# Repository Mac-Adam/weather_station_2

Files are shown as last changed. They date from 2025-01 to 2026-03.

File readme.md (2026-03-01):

## 3D Printable weather station

This is the repository for my personal project, a weather station.
It is based on ESP32. You can view the source code in the weather station folder.
All the 3d models are available in the 3d models folder.
Folder old has the program for an older version of the design.
Folder tests has a few programs created to calibrate or test individual components.
The stations has following functionality:

- Temperature, humidity and pressure sensor
- Air quality sensor
- Custom wind speed meter
- Custom wind direction meter
- Custom rain meter with heating to measure snow

## Building And Running

Open the Weather_station project in arudino studio and program your ESP32.
Before programing, create a secrets.ino file:

```

#ifndef SECRETS

#define WIFINAME "Name of your WiFi"
#define PASSWORD "Your WiFi Password"
#define ID Unique ID
#define SERVERNAME "Url for your server"
#else

#define SECRETS
#endif
```

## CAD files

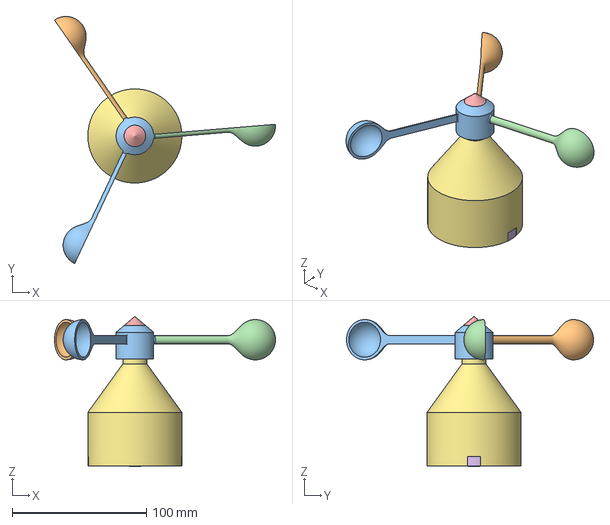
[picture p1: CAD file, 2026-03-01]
3dModels/assembly_speed.3mf
164.5 x 183.9 x 111.7 mm

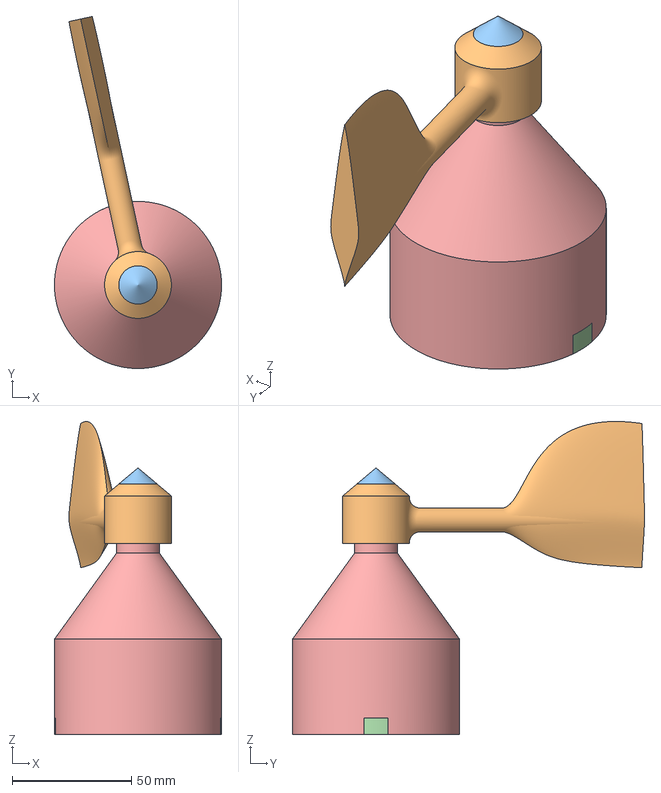
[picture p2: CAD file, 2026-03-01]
3dModels/assembly_direction.3mf
70.0 x 147.5 x 131.2 mm
new_shaft

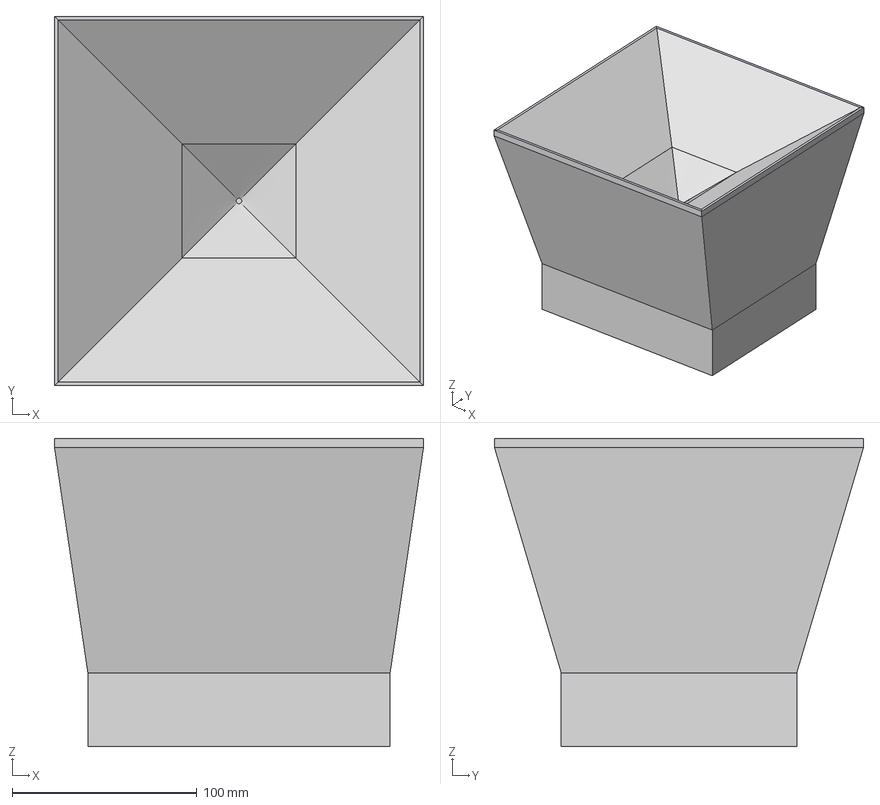
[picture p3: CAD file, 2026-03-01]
3dModels/assembly_rain.3mf
200.0 x 200.0 x 167.0 mm
base
inner1
inner2
inner3
inner4
inner_mid
outer1
outer2
outer3
outer4

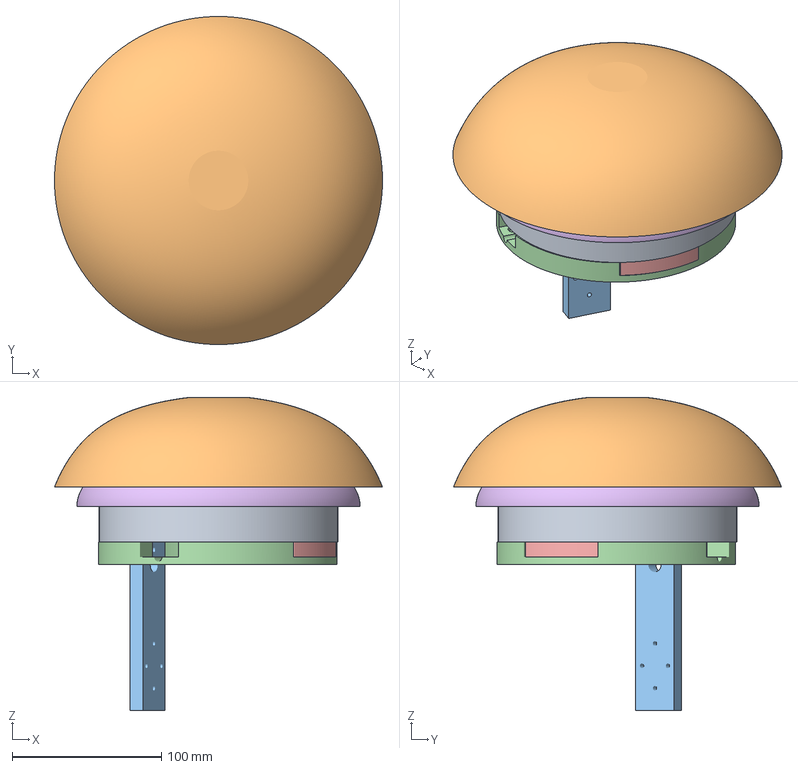
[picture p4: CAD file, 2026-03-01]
3dModels/assembly_hub.3mf
220.0 x 220.0 x 210.0 mm

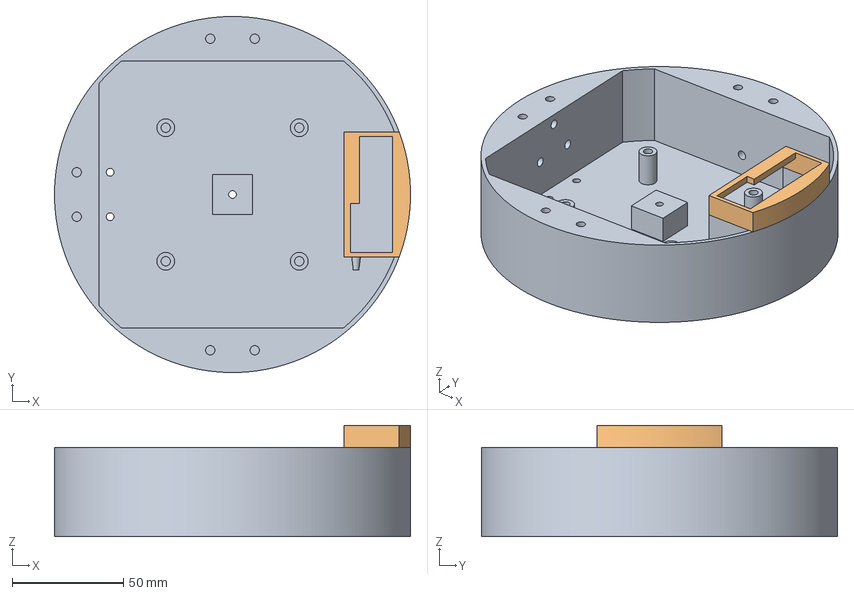
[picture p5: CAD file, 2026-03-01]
3dModels/hub/base_full.3mf
160.0 x 160.0 x 50.0 mm

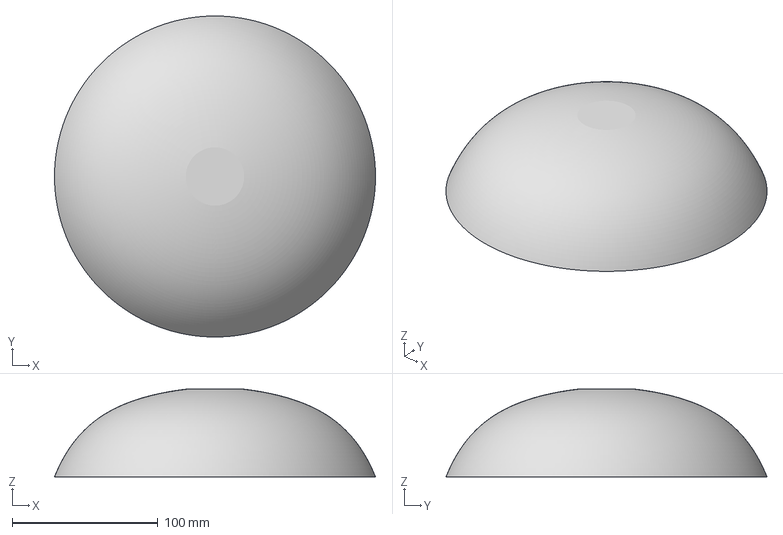
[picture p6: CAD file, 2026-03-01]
3dModels/hub/hat_1.3mf
220.0 x 220.0 x 60.0 mm

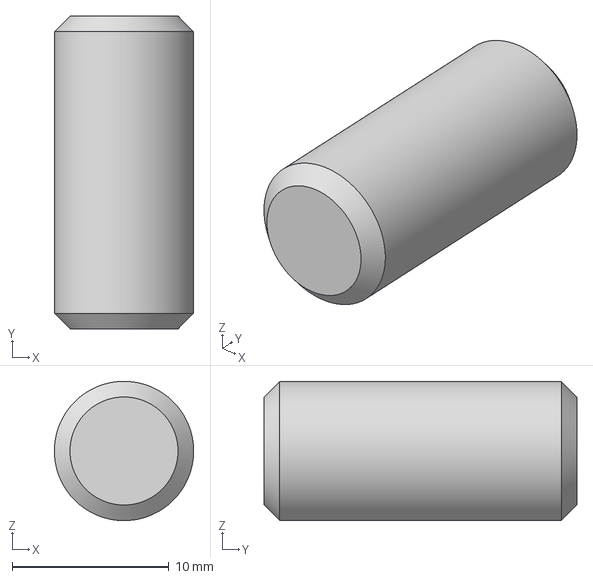
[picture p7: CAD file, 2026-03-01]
3dModels/rain/pin.3mf
8.90 x 20.0 x 8.90 mm

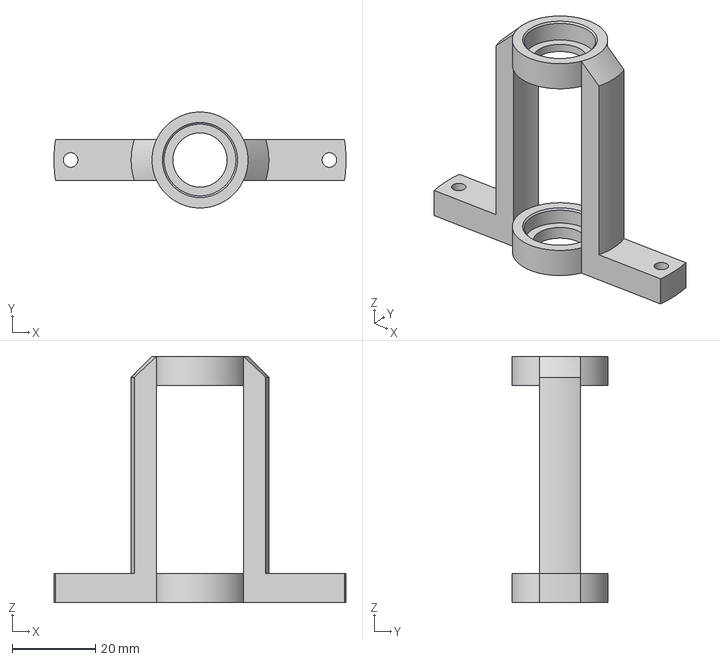
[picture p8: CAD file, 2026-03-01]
3dModels/wind/base_direction.3mf
70.0 x 23.0 x 59.0 mm

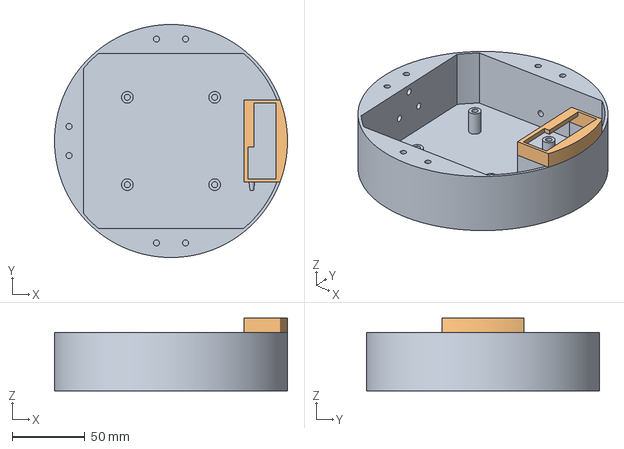
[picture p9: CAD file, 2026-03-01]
3dModels/hub/base_minimal.3mf
160.0 x 160.0 x 50.0 mm

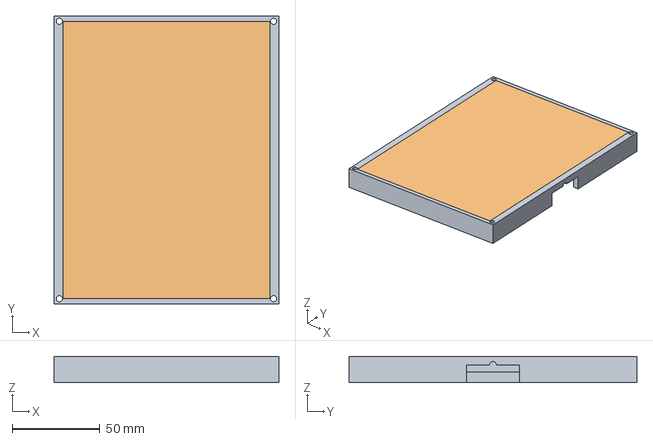
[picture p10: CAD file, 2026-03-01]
3dModels/rain/cover.3mf
128.0 x 164.0 x 15.0 mm

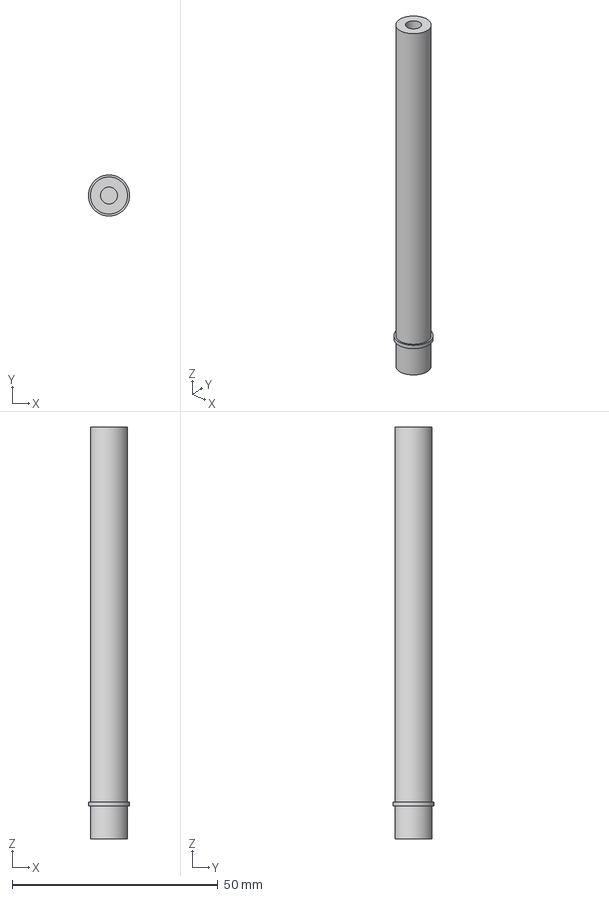
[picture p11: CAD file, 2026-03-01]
3dModels/wind/shaft_direction.3mf
10.0 x 10.0 x 100.0 mm

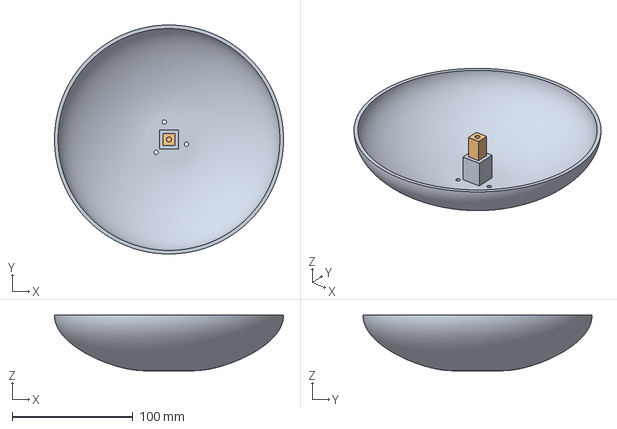
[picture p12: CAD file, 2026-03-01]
3dModels/hub/hat_2.3mf
190.0 x 190.0 x 46.1 mm

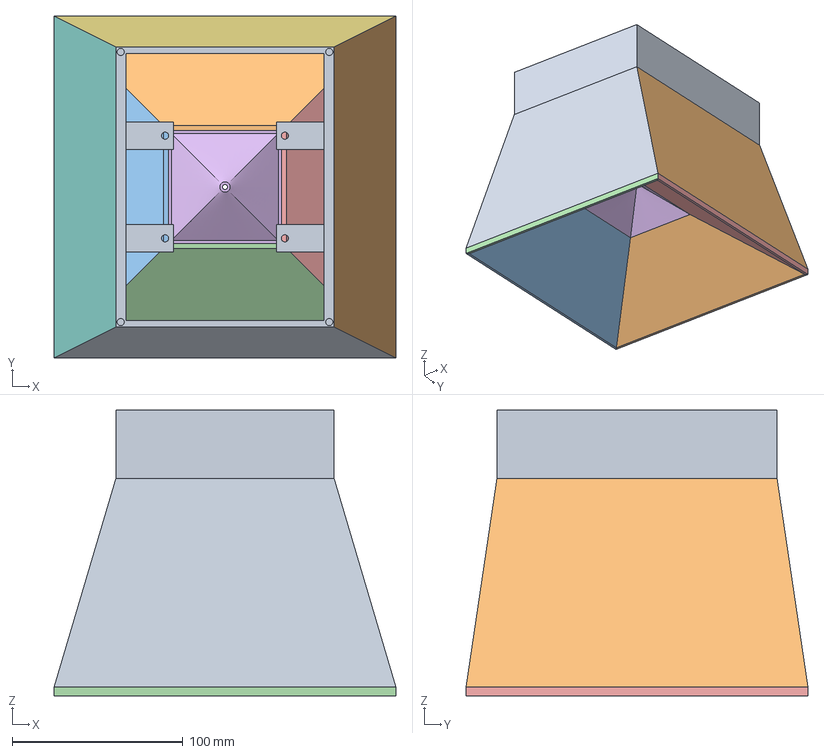
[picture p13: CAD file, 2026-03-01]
3dModels/rain/funnel.3mf
200.0 x 200.0 x 167.0 mm
base
inner1
inner2
inner3
inner4
inner_mid
outer1
outer2
outer3
outer4

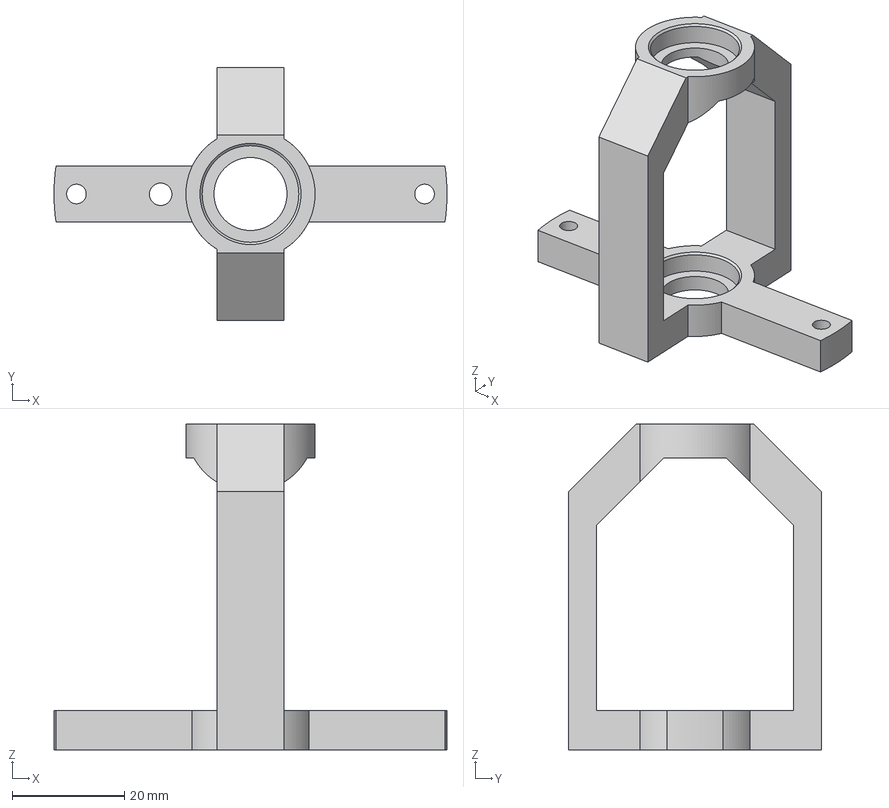
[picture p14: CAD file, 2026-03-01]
3dModels/wind/base_speed.3mf
70.0 x 45.0 x 58.0 mm

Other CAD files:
3dModels/hub/cover.3mf
3dModels/rain/pools.3mf
3dModels/wind/cover.3mf
3dModels/rain/mout.3mf
3dModels/hub/cover_minimal.3mf
3dModels/hub/mount.3mf
3dModels/rain/body.3mf
3dModels/rain/maget_holder.3mf
3dModels/rain/pin_holder.3mf
3dModels/wind/mount.3mf
3dModels/wind/shaft_speed.3mf
3dModels/wind/top_cover.3mf
3dModels/wind/top_direction.3mf
3dModels/wind/top_speed.3mf

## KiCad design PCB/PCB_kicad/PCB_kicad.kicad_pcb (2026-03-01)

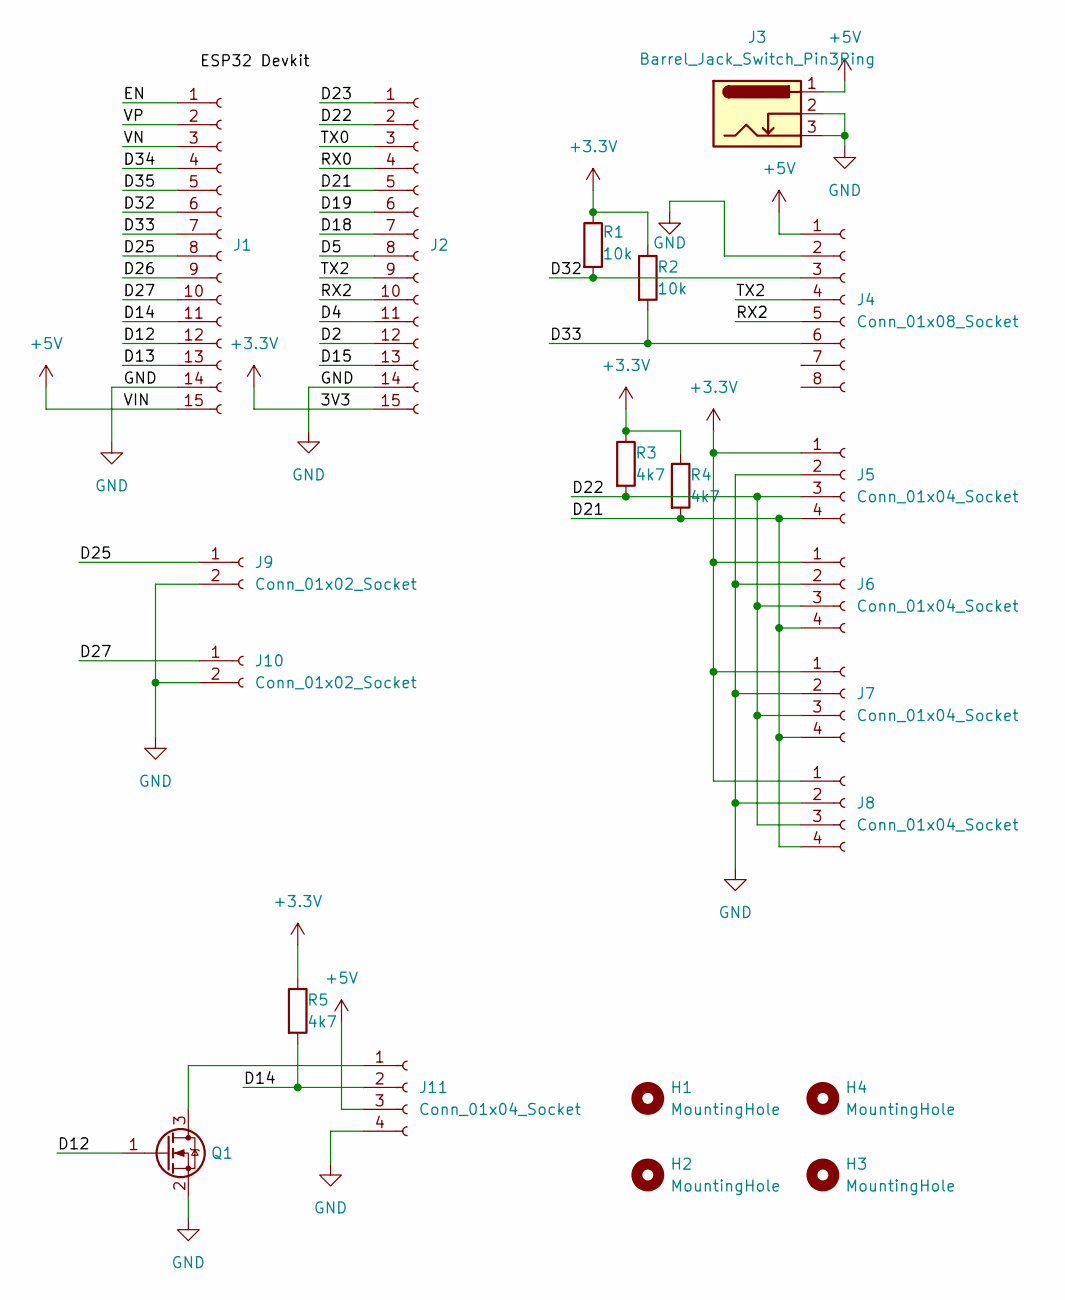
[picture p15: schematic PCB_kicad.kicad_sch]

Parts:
H1, H2, H3, H4: MountingHole; MountingHole_3.2mm_M3
J1, J2: Conn_01x15_Socket; PinHeader_1x15_P2.54mm_Vertical
J3: Barrel_Jack_Switch_Pin3Ring; BarrelJack_Horizontal
J4: Conn_01x08_Socket; Molex_PicoBlade_53047-0810_1x08_P1.25mm_Vertical
J5, J6, J7, J8, J11: Conn_01x04_Socket; PinHeader_1x04_P2.54mm_Vertical
J9, J10: Conn_01x02_Socket; PinHeader_1x02_P2.54mm_Vertical
Q1: 2N7002; SOT-23
R1, R2: 10k; R_Axial_DIN0204_L3.6mm_D1.6mm_P7.62mm_Horizontal
R3, R4, R5: 4k7; R_Axial_DIN0204_L3.6mm_D1.6mm_P7.62mm_Horizontal

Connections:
+3.3V: J2.15, J5.1, J6.1, J7.1, J8.1, R1.1, R2.1, R3.1, R4.1, R5.1
+5V: J1.15, J3.1, J4.1, J11.3
/D2: J2.12
/D4: J2.11
/D5: J2.8
/D12: J1.12, Q1.1 (G)
/D13: J1.13
/D14: J1.11, J11.2, R5.2
/D15: J2.13
/D18: J2.7
/D19: J2.6
/D21: J2.5, J5.4, J6.4, J7.4, J8.4, R4.2
/D22: J2.2, J5.3, J6.3, J7.3, J8.3, R3.2
/D23: J2.1
/D25: J1.8, J9.1
/D26: J1.9
/D27: J1.10, J10.1
/D32: J1.6, J4.3, R1.2
/D33: J1.7, J4.6, R2.2
/D34: J1.4
/D35: J1.5
/EN: J1.1
/RX0: J2.4
/RX2: J2.10, J4.5
/TX0: J2.3
/TX2: J2.9, J4.4
/VN: J1.3
/VP: J1.2
GND: J1.14, J2.14, J3.2, J3.3, J4.2, J5.2, J6.2, J7.2, J8.2, J9.2, J10.2, J11.4, Q1.2 (S)
unnamed: J11.1, Q1.3 (D)

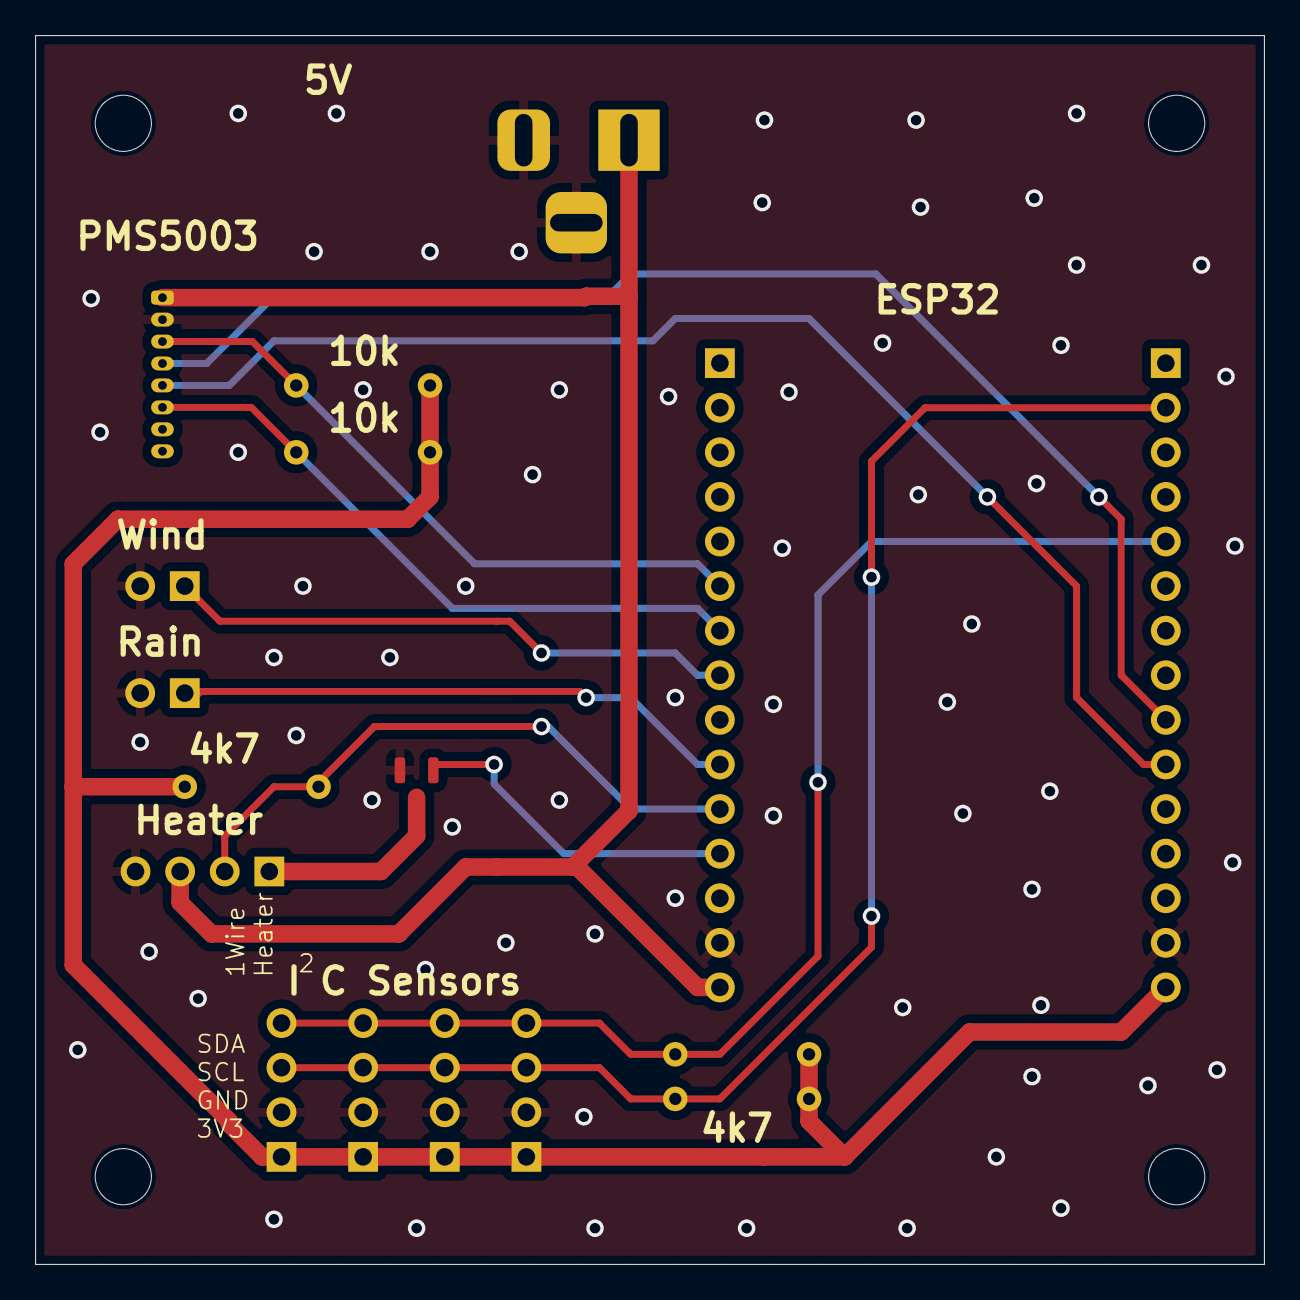
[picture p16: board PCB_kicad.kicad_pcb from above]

Board: 2 copper layers, 70.0 x 70.0 mm, 21 parts (0 on the bottom side), 14 nets.

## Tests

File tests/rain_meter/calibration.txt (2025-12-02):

Calibrate the rain meter sensor, check how much water is needed in order to overflow the mechanism.
In order to get a accurate reading, make at least 10 measurements. 

divide the value im ml by area of the  funnel in cm^2.

stare - 11.1 ml - 0,2775
nowe - 12.5 ml - 0,3125
nowsze - 6 ml - 0,15

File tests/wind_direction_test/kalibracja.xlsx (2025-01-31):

X | Y | Z | X Norm | Y Norm
-97 | 775 | -1425 | -0.1441155743 | 0.4044776119 |  |  |  |  |  | 0.01 | 0.004999916667 | 0.4999750002
-80 | 777 | -1442 | -0.1321353066 | 0.4056716418 |  |  |  |  |  | 0.02 | 0.009999333347 | 0.4999000033
-77 | 760 | -1452 | -0.1300211416 | 0.3955223881 |  | X | Y | X Nomr | Y Norm | 0.03 | 0.0149977501 | 0.4997750169
-85 | 760 | -1430 | -0.1356589147 | 0.3955223881 | AVG | 214.0576827 | 124.4888115 | 0.0750935044 | 0.01611272331 | 0.04 | 0.01999466709 | 0.4996000533
-87 | 762 | -1425 | -0.137068358 | 0.3967164179 | Max | 817 | 935 | 0.5 | 0.5 | 0.05 | 0.02498958464 | 0.4993751302
-87 | 790 | -1430 | -0.137068358 | 0.4134328358 | Min | -602 | -740 | -0.5 | -0.5 | 0.06 | 0.02998200324 | 0.49910027
-140 | 807 | -1407 | -0.1744186047 | 0.4235820896 | Dif | 1419 | 1675 | 1 | 1 | 0.07 | 0.03497142367 | 0.4987755001
-212 | 832 | -1357 | -0.2251585624 | 0.4385074627 | Off | 107.5 | 97.5 | 0 | 0 | 0.08 | 0.03995734698 | 0.4984008532
-175 | 830 | -1370 | -0.1990838619 | 0.4373134328 |  |  |  |  |  | 0.09 | 0.0449392746 | 0.4979763665
-170 | 832 | -1405 | -0.1955602537 | 0.4385074627 |  |  |  |  |  | 0.1 | 0.04991670832 | 0.4975020826
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

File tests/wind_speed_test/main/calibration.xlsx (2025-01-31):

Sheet: Do10 (2)
V | RPM DO | RMP OD | AVG | VAR
10 | 52.3 | 59.9 | 56.1 | 3.8
15 | 95.9 | 104.1 | 100 | 4.1
20 | 141.7 | 130 | 135.85 | 5.85
25 | 199.7 | 190.6 | 195.15 | 4.55
30 | 253.8 | 265.8 | 259.8 | 6
35 | 322.4 | 295.5 | 308.95 | 13.45
40 | 367.2 | 335 | 351.1 | 16.1
45 | 418 | 372 | 395 | 23
 | 10.02797619 | -50.52559524
 | 0.2708043243 | 8.067514894
 | 0.9956434801 | 8.775063028
 | 1371.246077 | 6
 | 105588.3218 | 462.0103869

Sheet: Do10
Do 10km/h

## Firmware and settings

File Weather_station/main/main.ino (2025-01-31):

#include "secrets.ino"
#include "config.ino"
#include "meters.ino"

#include <WiFi.h>
#include <HTTPClient.h>



hw_timer_t * timerDir = NULL; 
hw_timer_t * timerSend = NULL; 

unsigned long t = 0;
unsigned long t2 = 0;
int interupts = 0;



void connetcToWiFi(){
  
  if (!WiFi.config(local_IP, gateway, subnet, primaryDNS, secondaryDNS)) {
#if DEBUG
    Serial.println("STA Failed to configure");
#endif
  }
#if DEBUG
  Serial.print("Connecting to: ");
  Serial.println(WIFINAME);
#endif
  WiFi.begin(WIFINAME, PASSWORD);
  while (WiFi.status() != WL_CONNECTED) {
#if DEBUG
    Serial.println("connceting to WiFi");
#endif
    delay(1000);
  }
#if DEBUG
  Serial.println("Connected to wifi");
  Serial.println("IP address: ");
  Serial.println(WiFi.localIP());
#endif
}


void IRAM_ATTR SendDataInterupt(){
  readData = true;
}


void setup() {
  Wire.begin();
#if DEBUG
  Serial.begin(115200); // for testing
#endif
  Serial2.begin(9600, SERIAL_8N1, 16, 17); // for comunication wint pms 5003

  Wire.begin();

  connetcToWiFi();

  pms.passiveMode();

  if(!bme.begin(0x76)){
#if DEBUG
    Serial.println("Failed to find BME280 sensor");
#endif
    bmeError = true;
  }
#if HEATER
  sensors.begin();
  numberOfDevices = sensors.getDeviceCount();
#if DEBUG
  Serial.print("Locating devices...");
  Serial.print("Found ");
  Serial.print(numberOfDevices, DEC);
  Serial.println(" devices.");

  for(int i=0;i<numberOfDevices; i++){
    if(sensors.getAddress(tempDeviceAddress, i)){
      Serial.print("Found device ");
      Serial.print(i, DEC);
      Serial.print(" with address: ");
      printAddress(tempDeviceAddress);
      Serial.println();
    } else {
      Serial.print("Found ghost device at ");
      Serial.print(i, DEC);
      Serial.print(" but could not detect address. Check power and cabling");
    }
  }
#endif
  pinMode(HEATER_PIN,OUTPUT);
  digitalWrite(HEATER_PIN,HIGH);
#endif


  pinMode(rainMeter.pin, INPUT_PULLUP);
  attachInterrupt(rainMeter.pin, PoolOverflowInterrupt, CHANGE);

#if !ENCODERWIND
  qmc.init();
  qmc.setMode(Mode_Continuous,ODR_200Hz,RNG_8G,OSR_256);
#endif

  pinMode(windSpeedMeter.pin, INPUT_PULLUP);
  attachInterrupt(windSpeedMeter.pin, WindSpeedInterupt, CHANGE);

  // periodic timer that will evoke the WindDirectionInterupt function every WINDDIRMEASUREMENTPERIODUS us
  timerDir = timerBegin(1000000);           	
  timerAttachInterrupt(timerDir, WindDirectionInterupt);
  timerAlarm(timerDir, WINDDIRMEASUREMENTPERIODUS, true,0);  		

  timerSend = timerBegin(1000000);           	
  timerAttachInterrupt(timerSend, SendDataInterupt);
  timerAlarm(timerSend, SENDPERIOD, true,0);  		

}

void loop() {

  if(readWindDir){
#if DEBUG
    Serial.println("Readning Wind");
#endif
#if HEATER
    sensors.requestTemperatures(); 
    float avg = 0;
    for(int i=0;i<numberOfDevices; i++){
      if(sensors.getAddress(tempDeviceAddress, i)){

        float tempC = sensors.getTempC(tempDeviceAddress);
        avg += tempC/numberOfDevices;
      }
    }
#if DEBUG
    Serial.print("Avreage reain meter temp: ");
    Serial.println(avg);
#endif
    if (avg > TARGET_T + HIST){
      digitalWrite(HEATER_PIN,LOW);
#if DEBUG
      Serial.println("Heating off");
#endif
    }else if (avg < TARGET_T - HIST){
      digitalWrite(HEATER_PIN,HIGH);
#if DEBUG
      Serial.println("Heating on");
#endif
    }
#endif
    readWindDir = false;
#if ENCODERWIND
    windDirMeter.angles[windDirMeter.currentReads] = offsetAngle(as5600.rawAngle() * AS5600_RAW_TO_DEGREES);
    windDirMeter.currentReads ++;
#else
    int x,y,z,a;
    qmc.read(&x,&y,&z,&a);
    double xNormalized = (x + DIRXOFFSET)/DIRXSCALE;
    double yNormalized = (y + DIRYOFFSET)/DIRYSCALE;
      
    windDirMeter.angles[windDirMeter.currentReads] = getAngle(xNormalized, yNormalized);
    windDirMeter.currentReads ++;

#endif
    readWindSpeed(&windSpeedMeter,1);

  }
  if(readData)
  {
    
#if DEBUG
    Serial.println("Preparing to read data");
#endif

    WindMeterData windSpeed = readWindSpeed(&windSpeedMeter);
    WindDirData windDir = readDirection(&windDirMeter);
    double rain = readRain(&rainMeter);
    pms.wakeUp();
    delay(WAITFORSTABLEDATA);
#if DEBUG
    Serial.println("Reading data");
#endif

    //detachInterrupt(digitalPinToInterrupt(rainMeter.pin));
    //detachInterrupt(digitalPinToInterrupt(windSpeedMeter.pin));
    pms.requestRead();

    float temp = bme.readTemperature();
    float pressure = bme.readPressure();
    float humidity = bme.readHumidity();
    float aparantTemp = getAparantTemp(temp, humidity, windSpeed.averageSpeed);
    if(pms.readUntil(pmsData)){
#if DEBUG
      Serial.print("wind speed: ");
      Serial.println(windSpeed.averageSpeed);
      Serial.print("gusts speed: ");
      Serial.println(windSpeed.averageGust);
      Serial.print("Wind dir: ");
      Serial.println(windDir.angle);
      Serial.print("wind dir std div: ");
      Serial.println(windDir.standardDiv);
      Serial.print("Rain: ");
      Serial.println(rain);
      Serial.print("PM 1.0 (ug/m3): ");
      Serial.println(pmsData.PM_AE_UG_1_0);
      Serial.print("PM 2.5 (ug/m3): ");
      Serial.println(pmsData.PM_AE_UG_2_5);
      Serial.print("PM 10.0 (ug/m3): ");
      Serial.println(pmsData.PM_AE_UG_10_0);
      Serial.print("Temperature: ");
      Serial.println(temp);
      Serial.print("Aparant Temperature: ");
      Serial.println(aparantTemp);
      Serial.print("Pressure: ");
      Serial.println(pressure / 100.0F);
      Serial.print("Humidity = ");
      Serial.println(humidity);
      Serial.println("pms read succesfull");
#endif
    }else{
#if DEBUG
      Serial.println("Some pms error has ocured");
#endif
    }

    //attachInterrupt(rainMeter.pin, PoolOverflowInterrupt, CHANGE);
    //attachInterrupt(windSpeedMeter.pin, WindSpeedInterupt, CHANGE);

    if (WiFi.status() != WL_CONNECTED) {
      connetcToWiFi();
    }
    HTTPClient http;
    http.begin(SERVERNAME);
    http.addHeader("Content-Type", "application/x-www-form-urlencoded");
    String request = "";
    request += "wilgotnosc=";
    request += String(humidity);
    request += "&temperatura=";
    request += String(temp);
    request += "&temp_odczu=";
    request += String(aparantTemp);
    request += "&pm_ae_1=";
    request += String(pmsData.PM_AE_UG_1_0);
    request += "&pm_ae_2_5=";
    request += String(pmsData.PM_AE_UG_2_5);
    request += "&pm_ae_10=";
    request += String(pmsData.PM_AE_UG_10_0);
    request += "&pm_sp_1=";
    request += String(pmsData.PM_SP_UG_1_0);
    request += "&pm_sp_2_5=";
    request += String(pmsData.PM_SP_UG_2_5);
    request += "&pm_sp_10=";
    request += String(pmsData.PM_SP_UG_10_0);
    request += "&id_stacji=";
    request += String(ID);
    request += "&cisnienie=";
    request += String(pressure / 100.0F);
    request += "&predkosc_wiatru=";
    request += String(windSpeed.averageSpeed);
    request += "&predkosc_porywow=";
    request += String(windSpeed.averageGust);
    request += "&kierunek_wiatru=";
    request += String(windDir.angle);
    request += "&std_div_kierunku=";
    request += String(windDir.standardDiv);
    request += "&opad=";
    request += String(rain);

    int httpResponseCode = http.POST(request);
    if (httpResponseCode > 0)
    {

      String response = http.getString();

#if DEBUG
      Serial.println(response);

      Serial.println("seems ok");
#endif
    }
    else {
#if DEBUG
      Serial.println("something went wrong");
#endif
    }
#if DEBUG
    Serial.println(httpResponseCode);
#endif
    http.end();
    


    pms.sleep();
    readData = false;

    

  }

}

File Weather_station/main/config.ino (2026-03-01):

#ifndef CONFIG
// Depending on your weather station set values here correctly

// set to 1 if you are using encoder based wind direction meter
// set to 0 if you are using magnetometer based wind direction meter
#define ENCODERWIND 1

#define HEATER 0

// debug mode - faster readings, outputs to Serial
#define DEBUG 0

//Pins 27 new, 26 old
#define RAINMETERPIN 27
#define WINDMETERPIN 25

#if HEATER
  #define RAIN_TEMP_PIN 14
  #define HEATER_PIN 12

  #define TARGET_T 2
  #define HIST 0.2
#endif 



#if DEBUG 
  #define WINDDIRMEASUREMENTPERIODUS 100000 //us
  #define SENDPERIOD 20000000 // us
  #define WAITFORSTABLEDATA 5000 //ms
#else
  #define WINDDIRMEASUREMENTPERIODUS 10000000 //us
  #define SENDPERIOD 600000000  // us
  #define WAITFORSTABLEDATA 30000 //ms
#endif

#define DEBOUNCEPERIOD 10000
#define DEBOUNCEPERIODRAIN 100000
#define MICROSPERSECOND 1000000.0
#define MILISPERSECOND 1000.0
#define SECONDSPERHOUR 3600.0
#define PI 3.1415

IPAddress local_IP(192, 168, 1, 167);
IPAddress gateway(192, 168, 1, 1);
IPAddress subnet(255, 255, 255, 0);
IPAddress primaryDNS(192, 168, 1, 1);
IPAddress secondaryDNS(8, 8, 8, 8);

#define CONFIG
#endif

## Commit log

2025-01-31 Initial commit
    This is all the code form the private repo but with secret data removed
    [calibration.xlsx, kalibracja.xlsx, mag-omni.csv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]
2025-02-05 3d models
    [base.stl, bearig_mount.stl, bearing_mount.f3d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]
2025-12-02 New PCB
    [PCB_kicad.kicad_pcb, PCB_kicad.kicad_sch]
2026-03-01 Improved stability
    Added some minor tweaks to improve the stability of the desing
    [PCB_kicad.kicad_pcb, PCB_kicad.kicad_sch, assembly_direction.3mf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]
